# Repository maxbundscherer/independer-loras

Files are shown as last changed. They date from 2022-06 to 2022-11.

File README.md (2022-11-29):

# Independer

This repository is about a device called **Independer**. An Open-Source Project.

**Encrypted messaging & data sharing** via LoRaS & inexpensive hardware (ESP32). **Independent from mobile network & WIFI**. We use cheap *ESP32s*, *LoRa antennas*, *3D prototyping*, *mini keyboards* and develop our own encrypted *protocol* together with *software*.

**This page is intended for developers** - please visit the [official website](https://a-sdr.org/independer) for more information. If you want to **join, or have an idea**, feel free to [write us](mailto:maximilian@bundscherer-online.de) or [start a discussion](https://github.com/maxbundscherer/independer-loras/discussions). The current state of development can be viewed on the [project board](https://github.com/maxbundscherer/independer-loras/projects/2).

Presentation             |  Prototype-Video
:-------------------------:|:-------------------------:
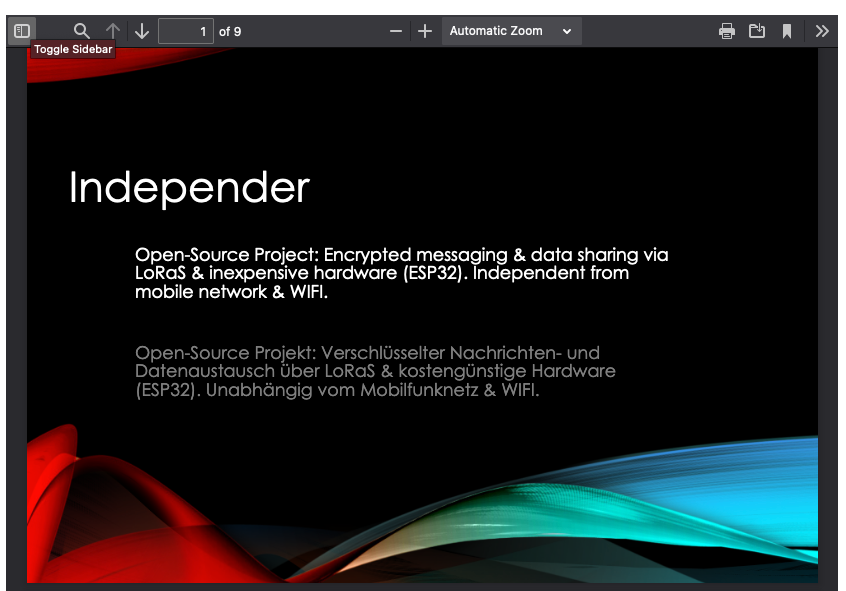
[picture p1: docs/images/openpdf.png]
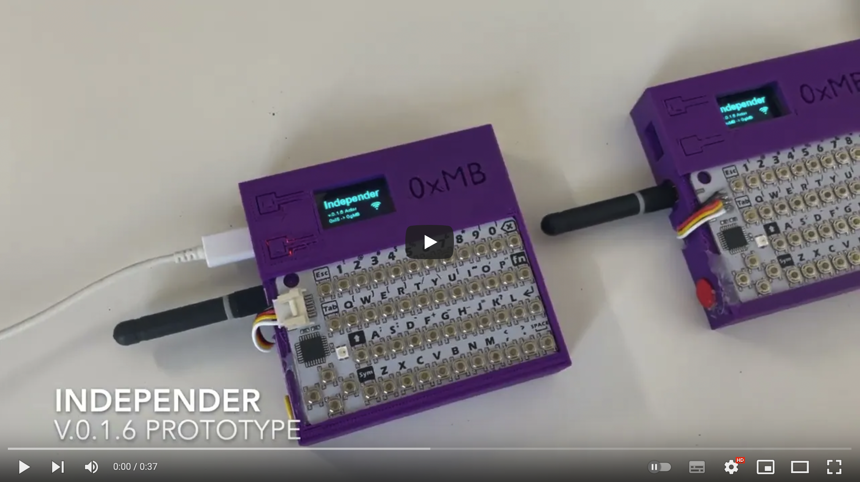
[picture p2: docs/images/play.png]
 | 

``esp32 - lora - encryption - short-message - protocol - keyboard - platformio - 3d-printing - independent``



Maintainer: [Maximilian Bundscherer](https://bundscherer-online.de)

## Overview

This repository describes the concept, the project structure, the encrypted LoraS transfer protocol (LoRaS) and the Independer application protocol. There are two type of devices: **Actor** (ID e.g. `0x01` or `0x02`) with keyboard & accumulator and **Gateway** (ID e.g. `0g01` or `0g02`) opt. with accumulator.

### Features

- **Actor to Actor (via LoRaS)**: Send messages directly between two Actors.
- **Actor to Gateway (via LoRaS)**: Send messages via Gateway. Actors can query their messages from Gateways.
- **Actor to Actor (via WIFI/Internet)**: Send messages via Internet. Actors can query their messages from WIFI/Internet.
- **Who is near me?** Scan the environment to find other Independers.
- **Many other functions**: Various test functions (Reachability Check, Reception & Transmission Evaluation), Update via WIFI, Notification LED, Deep Sleep Mode, Background-Sync, Battery Status, Send Quota & Gain, NTP-Time-Sync, Auto-Sync, Auto-Sleep, Contacts...

### Specifications

- Built on inexpensive Hardware
- Open-Source Software & Protocol
- Open-Source 3D-printed Case
- Multiple ESP32 boards, languages and frequencies are supported
- OLED-Screen
- LoRa & WIFI
- External Antenna Connector
- Mini Keyboard (QWERTY)
- 3000mAh LiPo Battery
- USB Charging (Micro-USB)

### Open-Source Project

Anyone can **contribute to the project** and **build their own device**. Many more features like GPS visualization, environment scanner, touch screen, alternative transmission and encryption functions are waiting **in the future**!

### Documentation

- [How-to, Hardware and Cost Overview](docs/howto.md)
- [Antenna Measurements](docs/antenna-measurements.md)
- [Update over WIFI](docs/update.md)
- [Developer Overview](docs/developer.md)
- [LoraS-Protocol](docs/loras-protocol.md)
- [Independer-Protocol](docs/independer-protocol.md)
- [Server-Protocol](docs/server-protocol.md)

The current state of development can be viewed on the [project board](https://github.com/maxbundscherer/independer-loras/projects/2).

### Included

- [Website](https://a-sdr.org/independer)
- [Documentation](docs/)
- [Sourcecode Independer ESP32 (C/C++)](independer-app/)
- [Sourcecode Independer Server (Python Flask Application)](independer-server/)
- [Docker Image Independer Server for Linux & Raspberry Pi](independer-server/)
- [3D-printed Case](case/)
- [Releases](https://github.com/maxbundscherer/independer-loras/releases/)

## More pictures

### Devices

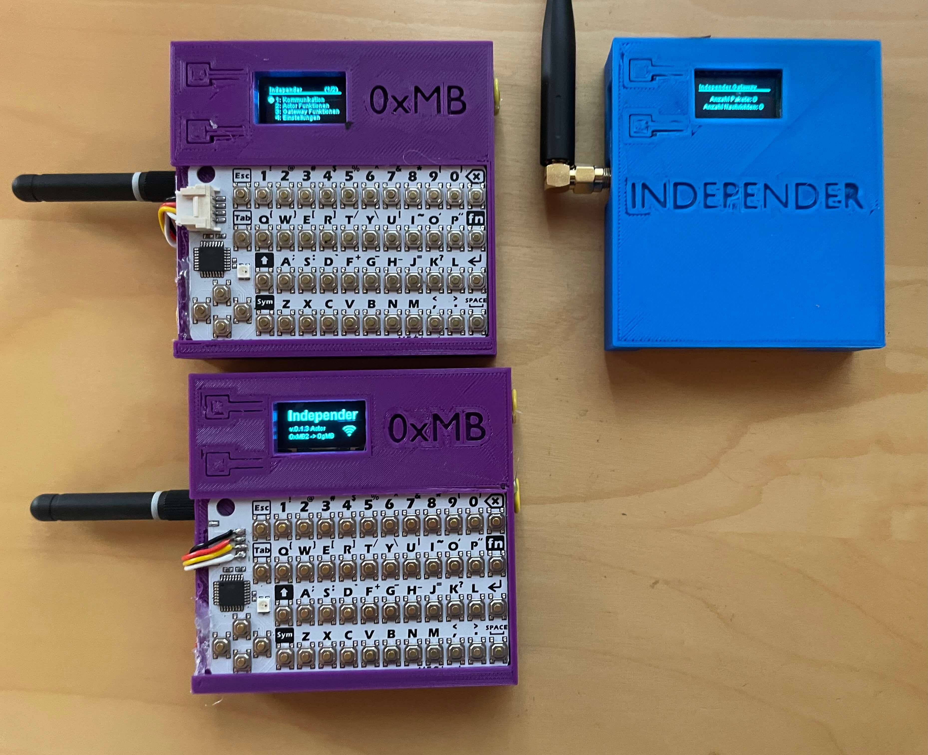
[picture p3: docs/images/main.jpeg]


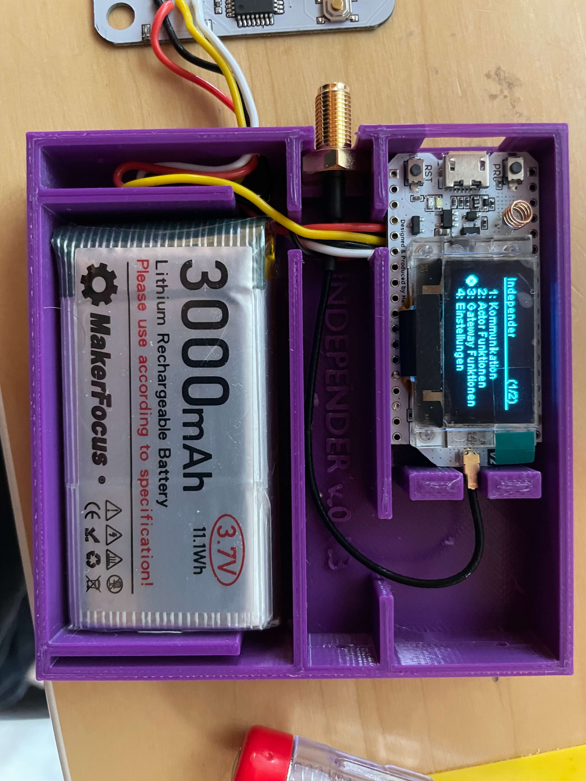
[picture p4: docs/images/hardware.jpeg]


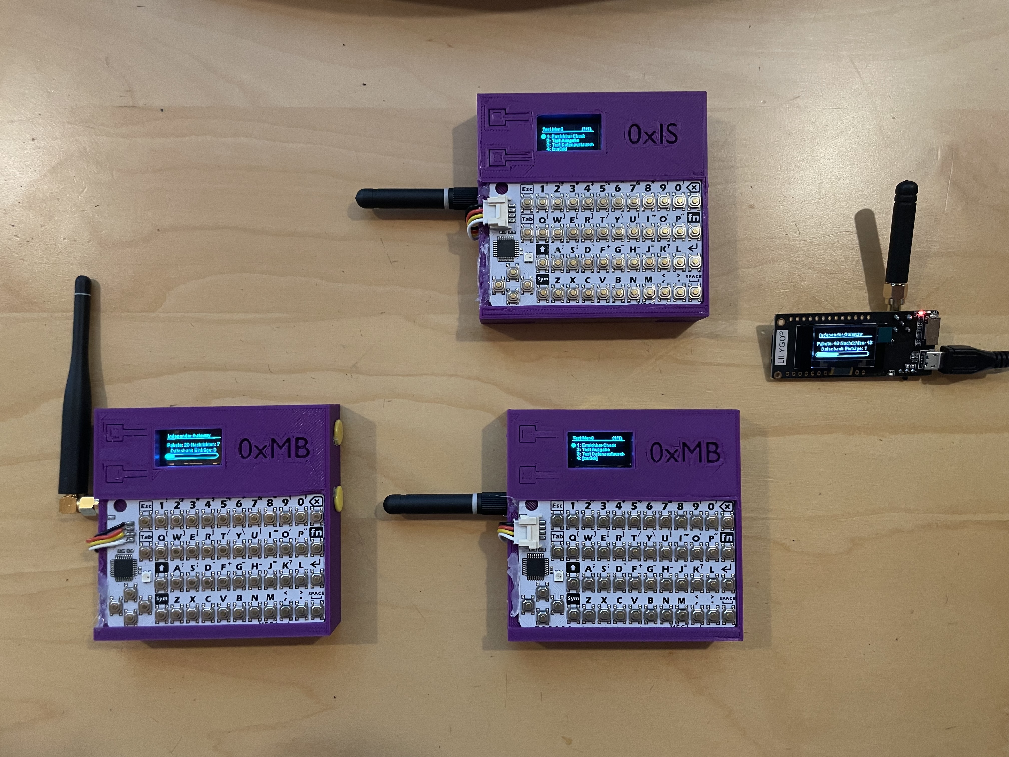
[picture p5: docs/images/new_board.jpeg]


### 3D Printing

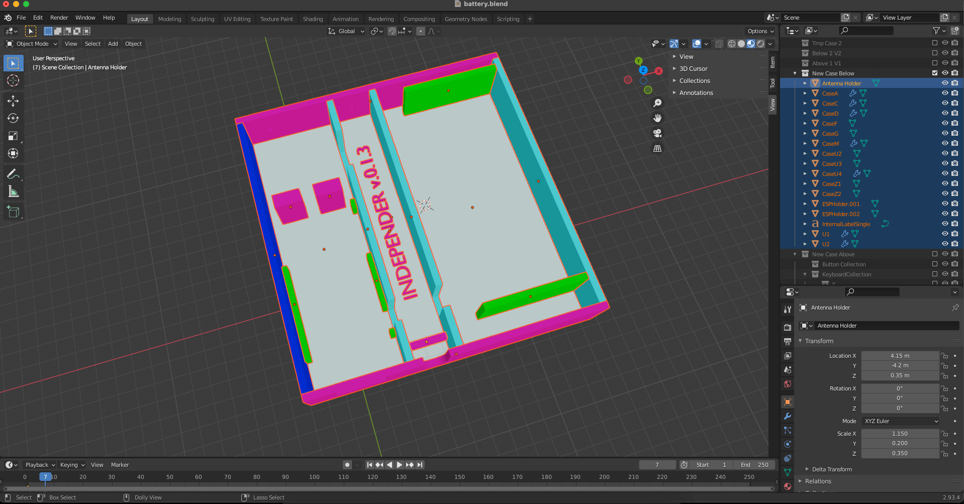
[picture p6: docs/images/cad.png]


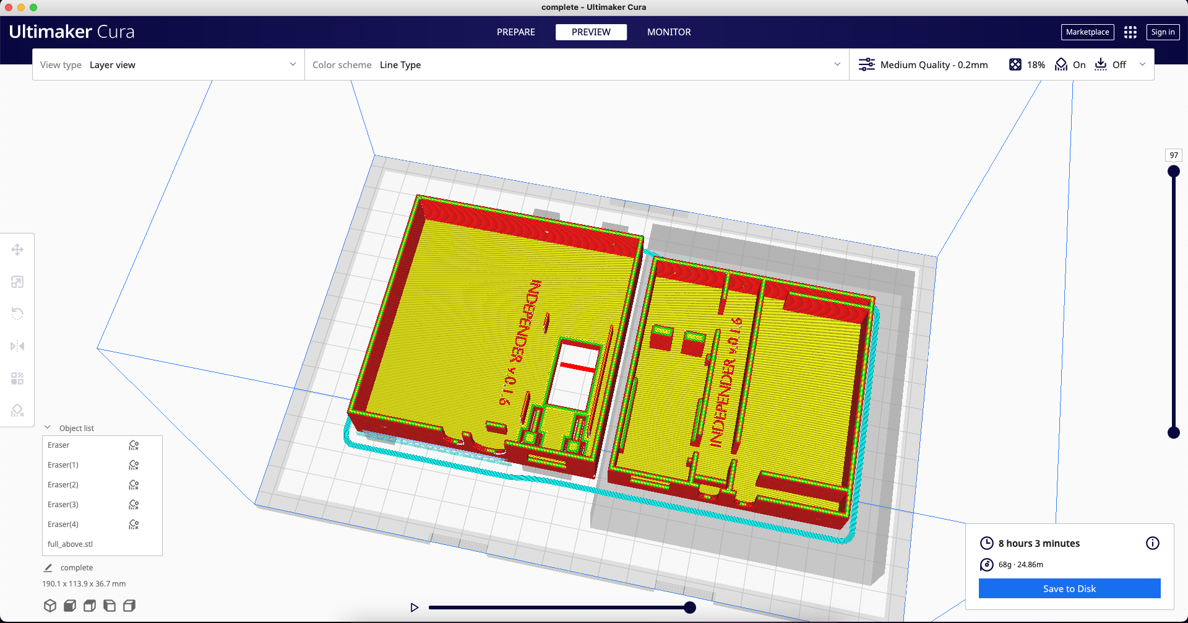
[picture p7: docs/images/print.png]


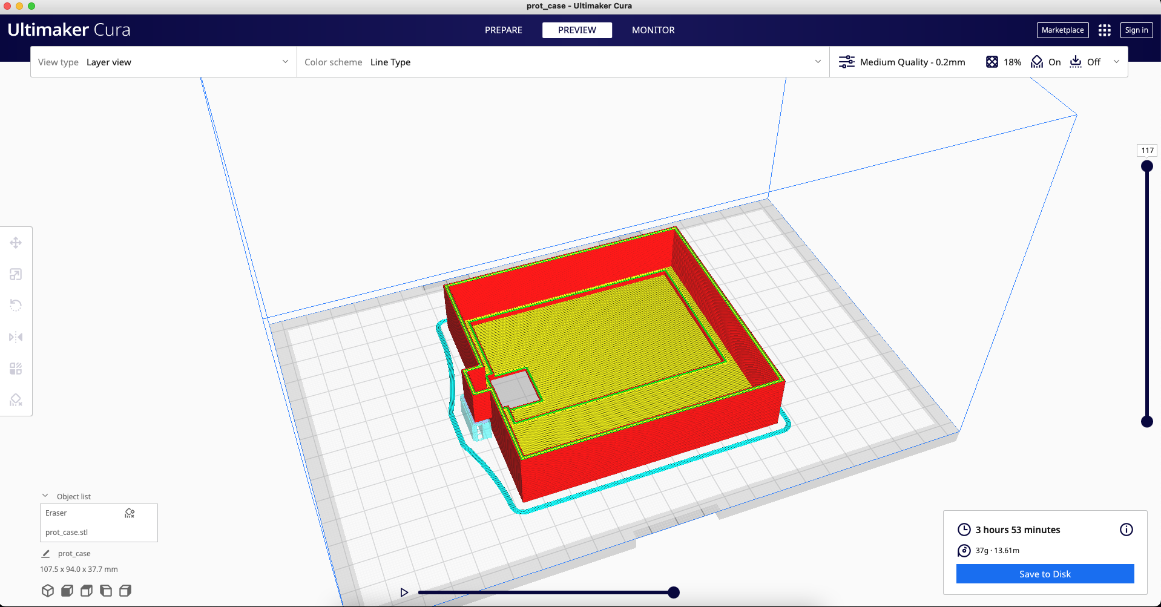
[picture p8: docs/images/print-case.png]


### UI

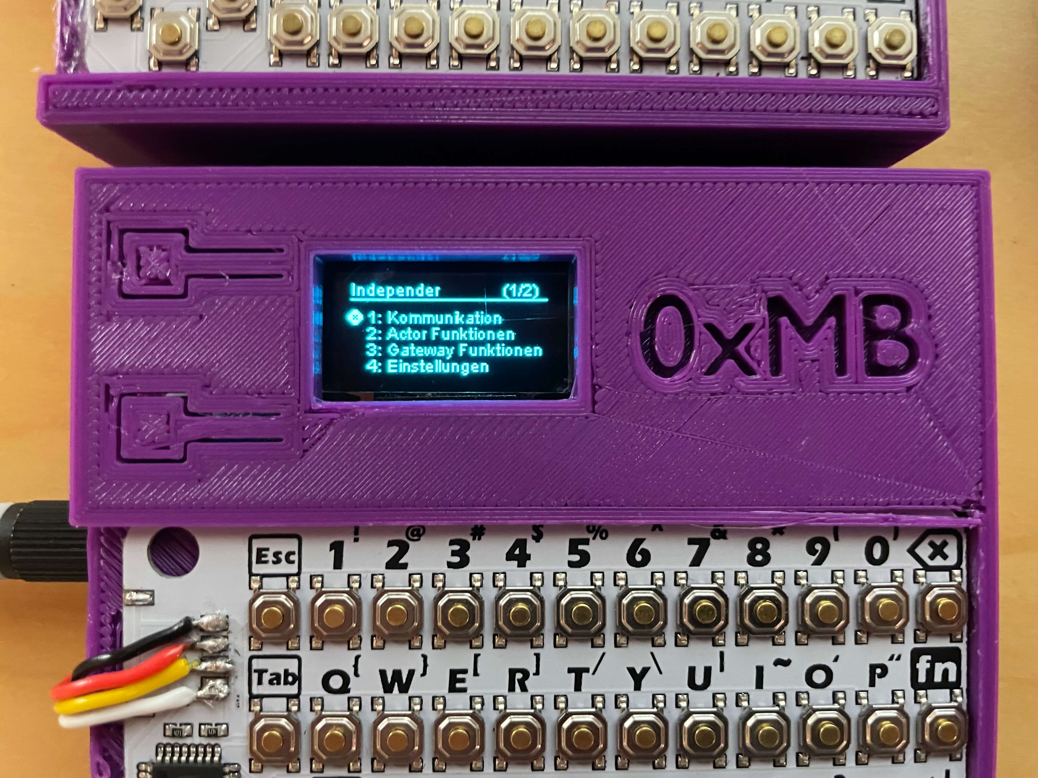
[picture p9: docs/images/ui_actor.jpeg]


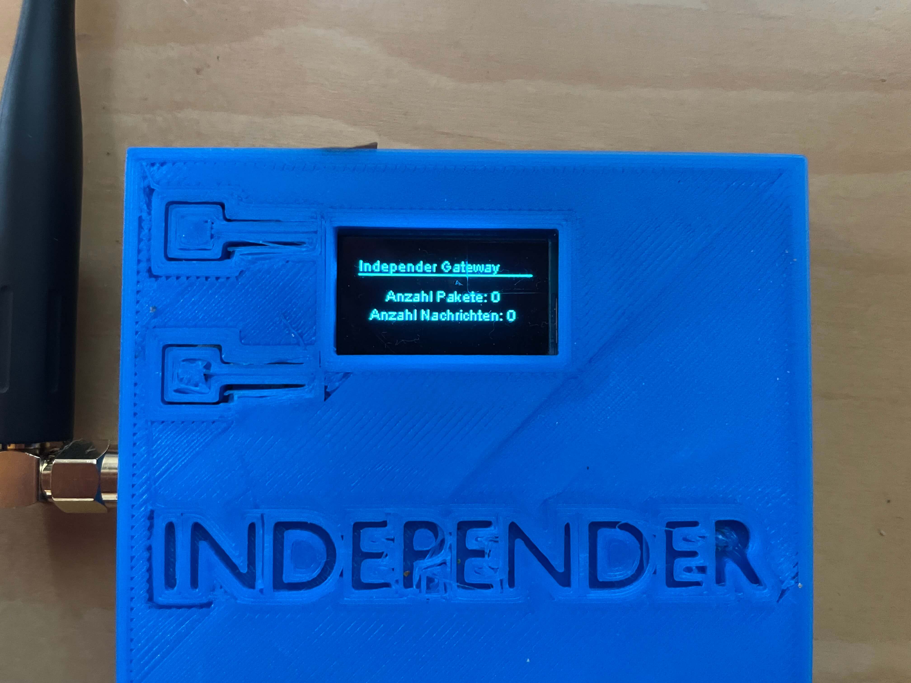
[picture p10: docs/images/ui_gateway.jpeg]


## Other

Also check out [Awesome/Automatic SDR](https://a-sdr.org/).

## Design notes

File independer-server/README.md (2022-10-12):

## Independer App Server

Docker is required.

### Run and Install

#### PreStep: Generate SSL Certificate

- `openssl req -x509 -newkey rsa:4096 -keyout key.pem -out cert.pem -sha256 -nodes` (set CN/FQDN to hostname)
- (Move `key.pem` and `cert.perm` to `./`)

#### Run

- Run `./run-raspbery.sh` on Raspberry Pi
- Run `./run-linux.sh` on Linux, macOs, etc.

##### Bugfix Raspberry TimeZone

If Postgres-Container does not sync time with Raspberry-Host - on Raspberry:

- `sudo vim /etc/apt/sources.list`
    - Add `deb http://raspbian.raspberrypi.org/raspbian/ testing main`
- `sudo apt-get update`
- `sudo apt-get install libseccomp2/testing`

#### Add Data

- Add Users and Gateways in table `users` and `gateways`
- Add System Info in table `systemdata`
    - `act_version`
    - `status_msg`

#### Config Network

- Config Router DNS to server (local ip)
- Config Router to forward port to server

### Status

- `docker ps -a`
- `docker compose ls`

### Stop and Clean

- Run `./clean-docker.sh`

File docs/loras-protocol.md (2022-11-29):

## LoRaS Protocol

This protocol is based on the **LoRa radio standard** and the transmission is currently **encrypted** with [boseji/xxtea-iot-crypt](https://registry.platformio.org/libraries/boseji/xxtea-iot-crypt). The goal will be an **asymmetric protocol like GPG**. Attention has always been paid to **low overhead**, **transmission security** and **energy saving**. The three protocols in this section are for LoRa receive and transmit (non-application level).

Currently the frequency **868 MHz** and **915 MHz** are used, but in the future the frequency **433 MHz** will also be usable. The frequencies are currently designed for the German area, but **can be freely selected**. Possible legal restrictions, such as the specified duty cycle and transmit power, can be taken into account, for example, using the *Send quota* and *Send gain* settings.

`[from]` and `[to]` in this section are realated to hardware-IDs, not application IDs. 

\[P1\] and \[P3\] are not suitable for background processing on actors. Please also visit [escape rules](escape-rules.md).

### Safe message \[P1\]

*Send message with hashcode-check*: Default protocol for e.g. Application messages.

`[num_packets]`, `[current_packet]`, and `[hashcode_msg]` are int-values.

- `[from]:[to]:+:[num_packets]`
- `[from]:[to]:[current_packet]:[part_of_msg]`
- `[from]:[to]:-:[hashcode_msg]`

### Unsafe short message \[P2\]

*Send short message without hashcode-check*: Default protocol for e.g. Who is in my area? or Is available?

Setting `[to]` to `*` addresses all devices in the environment.

- `[from]:[to]:s:[msg]`

### Unsafe single message \[P3\]

*Send single message without hashcode-check*: Default protocol for e.g. Respond to Who is in my area? and Is available?.

- `[from]:[to]:!:[msg]`

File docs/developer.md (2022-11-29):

## Developer Documentation

### Code Structure

The application is started through [PlatformIO](https://platformio.org/). Please set up parameters before compiling. Sourcecodes are located in `independer-app/src`.

- `device/`: Baseline LoRaS transmit & receive, Hardware stuff and UI.
- `workflow/`: Baseline workflow and examples for Actor and Gateway.
- `application/`: Baseline Independer application.

### Environments

- Environment label describes board-type (e.g. Heltec or TTGO), contains developer flag (release or developer), contains language flag and contains device-mode (actor or gateway).

#### Build and upload (single device)

- Select your specific PlatformIO-Enviroment.
- Run Task `Clean`
- Run Task `Build`
- Run Task `Upload`

#### Complete (all devices and all modes)

- Select no PlatformIO-Enviroment (global).
- Run Task `Clean`
- Run Task `Build`
- Run Script `independer-app/package.sh`
- View files in `independer-app/export/`

##### After Release (Release Workflow)

- Run previous steps.
- Merge `develop` into `master`.
- Create new release on GitHub (with files in `independer-app/export`).
- (Opt.) update Independer-Server.
- Increment Version in Independer-Server SQL-Table.
- Announcement new release (Signal, Facebook, Website, Product Presentation, GitHub)

### Upload code via WIFI

- See steps above.
- Upload ``independer-app/.pio/build/<BUILD-TYPE>/firmware.bin`` file via webbrowser (see update-doc).

### Additional Information

- [LoRa API](https://github.com/sandeepmistry/arduino-LoRa/blob/master/API.md)
- [Heltec LoRa API](https://github.com/HelTecAutomation/Heltec_ESP32/blob/master/src/lora/API.md)
- [Heltec API](https://github.com/HelTecAutomation/Heltec_ESP32/blob/master/src/oled/API.md)

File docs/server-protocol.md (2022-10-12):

## Server Protocol

JSON-API Independer Server. Please also visit [escape rules](escape-rules.md).

- `<server-url>/v1/register` (POST): Register Device
    - `id`: Independer-ID
    - `secret`: Secret
    - `version`: Version-String of Actor
    - Response `OK-<token>` (string, no json)

- `<server-url>/v1/getmsgs` (POST): Get all messages
    - `auth-id`: Independer-ID
    - `auth-token`: Token
    - Response (JSON-Array)
        - `receiver`: Receiver of the message
        - `author`: Author of the message
        - `msg`: Content of the message

- `<server-url>/v1/writemsg` (POST): Write a message
    - `auth-id`: Independer-ID
    - `auth-token`: Token
    - `receiver`: Receiver of the message
    - `msg`: Content of the message
    - Response `OK` (string, no json)

- `<server-url>/v1/clearmsgs` (POST): Clear all messages
    - `auth-id`: Independer-ID
    - `auth-token`: Token
    - Response `OK` (string, no json)

- `<server-url>/v1/gatewayregister` (POST): Check if Gateway is owned by the user
    - `auth-id`: Independer-ID
    - `auth-token`: Token
    - `gateway-id`: ID of Gateway
    - Response `OK` (string, no json) if allowed

- `<server-url>/v1/autosync` (POST): Get all messages
    - `auth-id`: Independer-ID
    - `auth-token`: Token
    - `version`: Version-String of Actor
    - `battery`: Battery mV of Actor
    - `time_before_sync`: Device time Actor before ntp sync
    - `time_after_sync`: Device time Actor after ntp sync
    - `dev_mode`: Dev mode activated
    - `is_actor`: IsActor
    - `wifi_ssid`: Wifi SSID
    - `boot_counts`: Boot Counts
    - Response (JSON-Array)
        - `num_msg`: Number of unread messages
        - `status_msg`: Status Broadcast
        - `act_version`: Independer-Version (last release)

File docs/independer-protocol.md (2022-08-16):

## Independer Protocol

Application level protocol is based on the [LoRaS Protocol](loras-protocol.md) \[P1\], \[P2\], and\[P3\]. Please also visit [escape rules](escape-rules.md).

### Based on Unsafe single message \[P3\]

#### Sleep Mode Gateway \[F3.1\]

This feature is used to set Gateway in sleep mode (Actor controlled).

1. For this Actor \[P3\] `[msg]` is set to `C;slp`. (send twice)

No available check before sending (\[F23.2\]). Gateway sends no response and goes into sleep mode. Gateway accepts these commands only from Gateway-Owner.

#### Clear User Messages on Gateway \[F3.2\]

This feature is used to clear user messages from Gateway (Actor controlled).

1. For this Actor \[P3\] `[msg]` is set to `C;clmsg`. (send twice)

No available check before sending (\[F23.2\]). Gateway sends no response and clears user messages.

#### Reset Gateway \[F3.3\]

This feature is used to reset Gateway.

1. For this Actor \[P3\] `[msg]` is set to `C;clgat`. (send twice)

No available check before sending (\[F23.2\]). Gateway sends no response and reset settings. Gateway accepts these commands only from Gateway-Owner.

### Based on Safe message \[P1\]

#### Update Gateway \[F1.1\]

This feature is used to update Gateway via wifi (Actor controlled).

1. For this Actor \[P1\] `[msg]` is set to `C;up;$wifiSSID;$wifiPW`. Where `$wifiSSID` is ssid from wifi and `$wifiPW` is wifi password.

No available check before sending (\[F23.2\]). Gateway sends no response and goes into update mode. Gateway accepts these commands only from Gateway-Owner.

#### Init Gateway \[F1.2\]

This feature is used to init Gateway via wifi (Actor controlled).

1. For this Actor \[P1\] `[msg]` is set to `C;init;$wifiSSID;$wifiPW;$id`. Where `$wifiSSID` is ssid from wifi, `$wifiPW` is wifi password and `$id` is gateway-id.

No available check before sending (\[F23.2\]). Gateway sends no response and initializes. Gateway-Owner is set from `[from]`.

### Based on Safe message \[P1\] and Unsafe single message \[P3\]

#### Send Message Actor to Gateway \[F13.1\]

This function is used to send messages via Gateway from Actor to Actor. This handles communication between Actor to Gateway (sending message).

1. For this Actor check if Gateway is available (\[F23.2\]).
2. If Gateway is available: Actor to Gateway \[P1\] `[msg]` is set to `M;$receiverId;$userMsg`. Where `$receiverId` is user-id from msg-receiver and `$userMsg` is actual message. Message author is derived from `[from]`.
3. Gateway to Actor \[P3\] `[msg]` is set to `A;ok`. (send twice)

If Actor does not receive a response from Gateway, Actor goes to step 2 (skip available check). This is repeated three times.

### Based on Unsafe single message \[P3\] and Safe message \[P1\]

#### Receive Messages Actor to Gateway to Actor \[F31.1\]

This function is used to send messages via Gateway from Actor to Actor. This handles communication between Actor to Gateway to Actor (receiving messages).

1. For this Actor \[P3\] `[msg]` is set to `Q;msg`. (send twice)
2. Gateway respond \[P1\] `[msg]` is set to `A;$numMessages;$msgAuthor1;$msgContent1;$msgAuthor2;$msgContent2;$msgAuthorN;$msgContentN`. Where `$numMessages` is number of message. If set `0` no messages are available. Messages with authors are appended to `[msg]` like `$msgAuthorN;$msgContentN`.  

No available check before sending (\[F23.2\]). This is repeated three times, if Actor receives no response from Gateway.

### Based on Unsafe short message \[P2\] and Unsafe single message \[P3\]

#### Who is in my area? \[F23.1\]

This function is used to find out which Actors and Gateways are nearby.

1. For this Actor \[P2\] `[to]` is set to `*` and `[msg]` is set to `?`.  (send twice)
2. Other devices (Actors and Gateways) respond randomly within 8 seconds \[P3\] and `[msg]` is set to `$battery-$rssi`. Where `$battery` is battery in mA and `$rssi` is rssi in dbi.

This is repeated threefold to reach and receive more devices. Designed for Actor background-job and Gateway.

#### Is available? \[F23.2\]

This function is used to find out whether a specific actor or gateway is nearby. Used mainly before sending a message over LoRaS.

1. For this Actor \[P2\] `[msg]` is set to `!`. (send twice)
2. Other device (Actors and Gateways) respond immedatly \[P3\] and `[msg]` is set to `$battery-$rssi`. Where `$battery` is battery in mA and `$rssi` is rssi in dbi. (send twice)

This function can be repeated. Designed for Actor background-job and Gateway.

### Based on Unsafe short message \[P2\], Safe message \[P1\] and Unsafe single message \[P3\]

#### Send Message Actor to Actor \[F213.2\]

This function is for sending messages directly between Actor A1 and Actor A2.

1. A1 (foreground) to A2 (background) \[P2\] `[msg]` is set to `T`. (send twice)
2. A2 reply to A1 \[P3\] `[msg]` is set to `S` and switch to foreground. (send twice)
3. A1 send data to A2 \[P1\] `[msg]` is set to `$msgContent`. Where `$msgContent` is content of message.
4. A2 replies to A1 \[P3\] `[msg]` is set to `N` and switch to background. (send twice)

Designed for Actor background-job. A1 tries whole process five times. A2 goes automatic in background if no data received from A1. If A2 receive data from step 1 - A2 reply \[P3\] to A1 `[msg]` is set to `S` again.

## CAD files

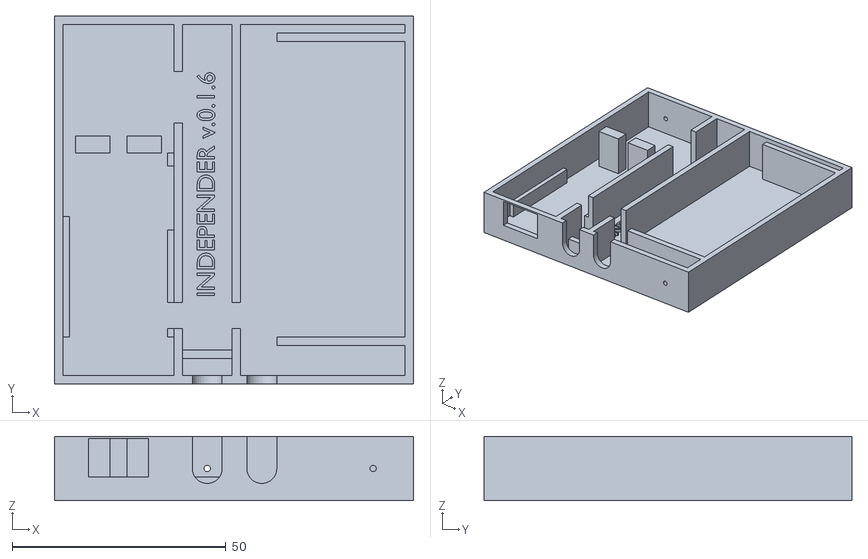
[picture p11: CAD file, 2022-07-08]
case/export/full_below.stl
84.0 x 86.0 x 15.0

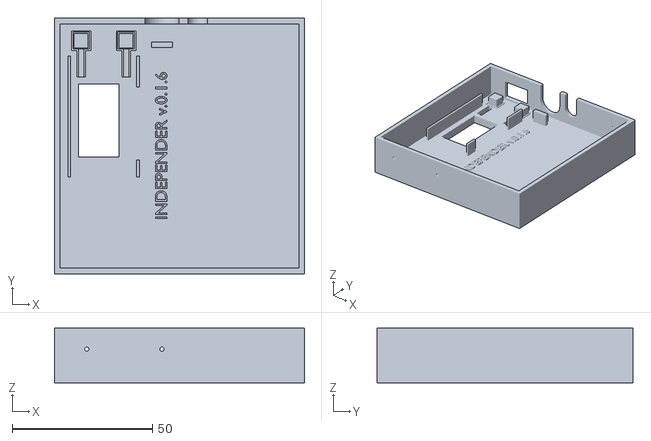
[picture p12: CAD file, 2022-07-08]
case/export/full_above.stl
89.0 x 91.0 x 19.5

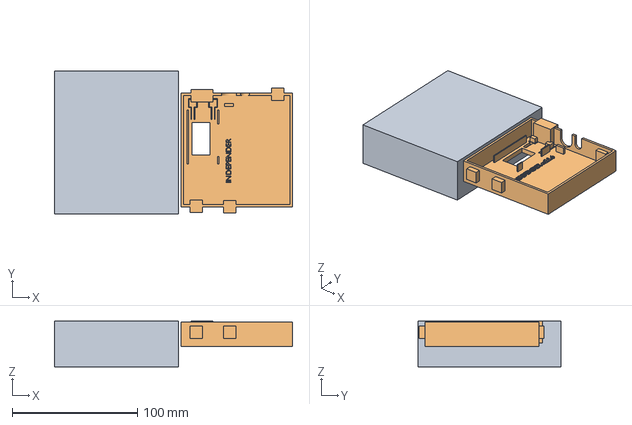
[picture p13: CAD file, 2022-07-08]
case/export/printer/complete.3mf
190.1 x 113.9 x 36.7 mm
full_below.stl
full_above.stl

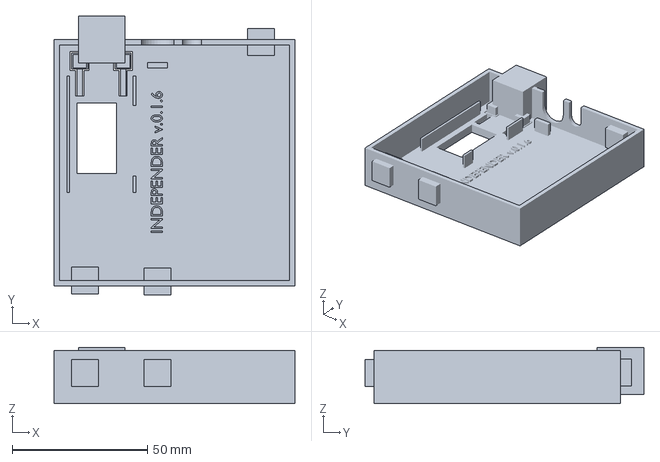
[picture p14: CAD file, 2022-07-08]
case/export/printer/full_above.3mf
89.0 x 102.9 x 20.7 mm

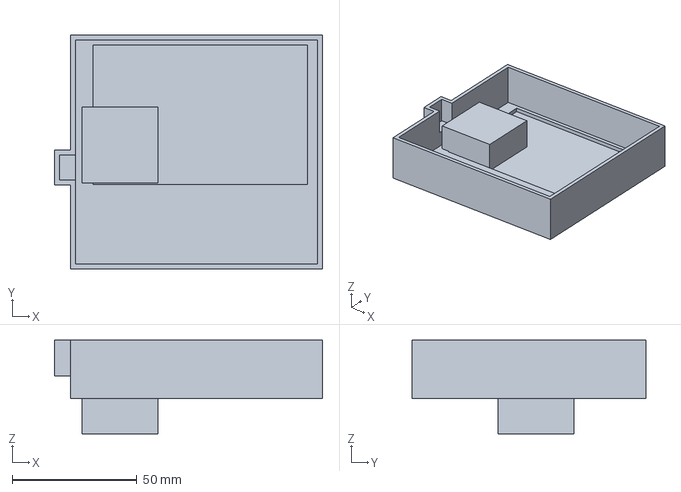
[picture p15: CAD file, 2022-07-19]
case/export/printer/prot_case.3mf
107.5 x 94.0 x 37.7 mm

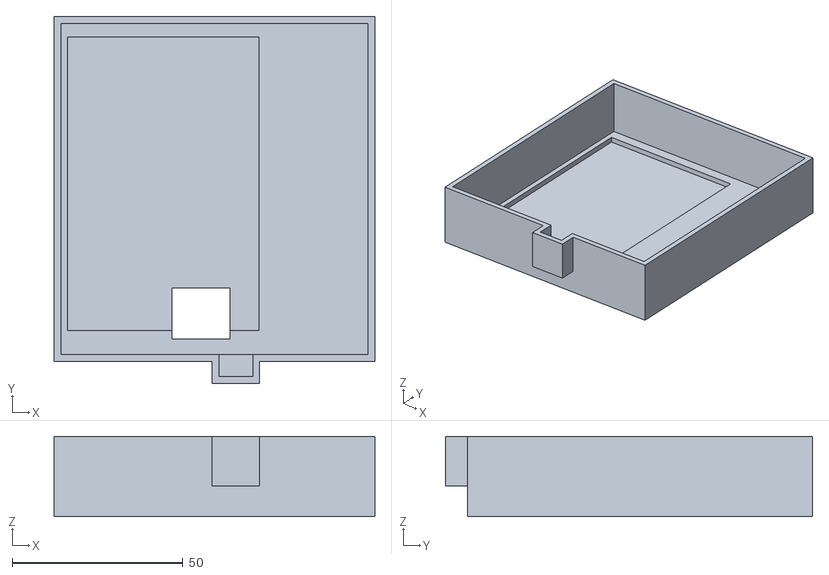
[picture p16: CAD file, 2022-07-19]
case/export/prot_case.stl
94.0 x 107.5 x 23.5

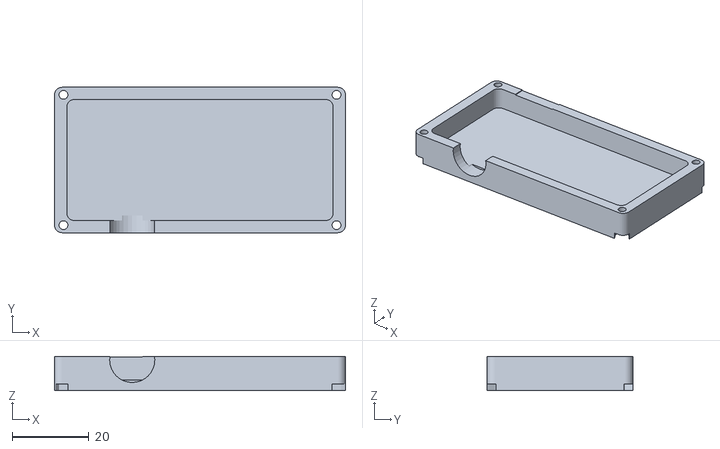
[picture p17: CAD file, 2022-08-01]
case/ttgo-case/LoRa-T3_case-bottom.stl
76.0 x 38.0 x 9.00

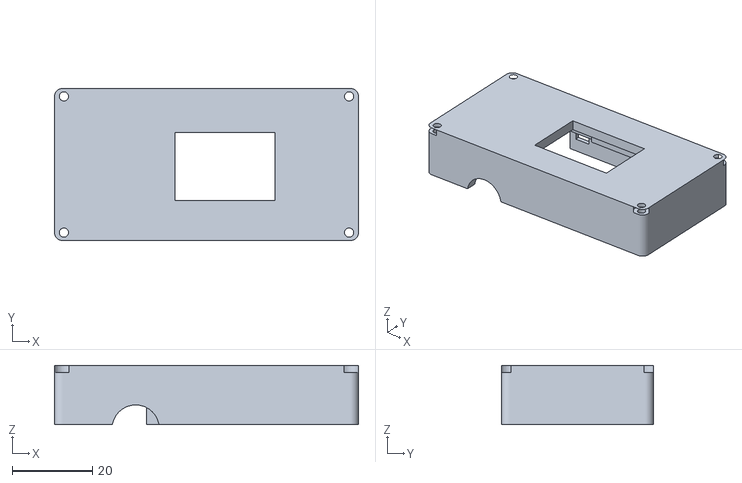
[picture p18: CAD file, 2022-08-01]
case/ttgo-case/LoRa-T3_case-cover.stl
76.0 x 38.0 x 14.8

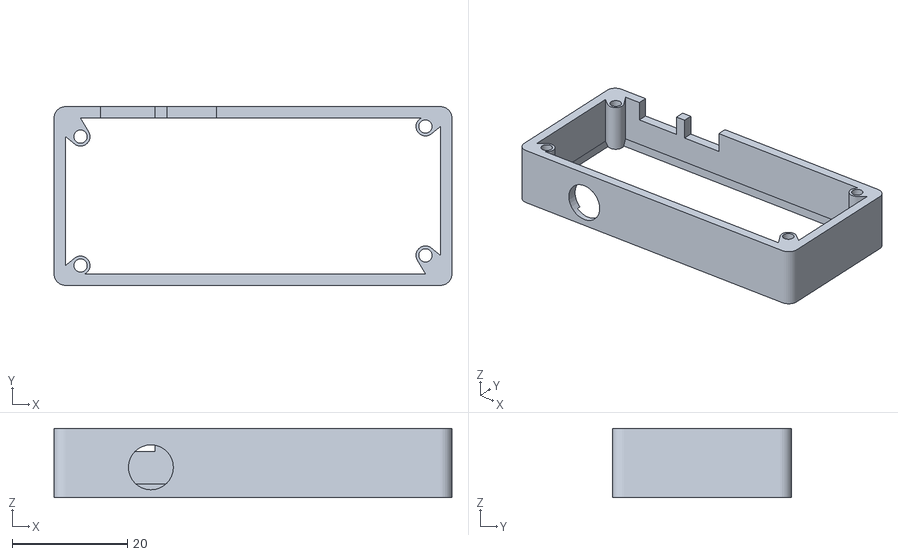
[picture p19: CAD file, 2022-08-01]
case/ttgo-case/LoRa-T3_case-inlay.stl
69.0 x 31.0 x 12.0

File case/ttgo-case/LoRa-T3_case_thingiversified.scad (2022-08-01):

// choose part to render
//part                = "case_inlay";
part                = "case_all";
//part                = "case_cover";
//part                = "case_bottom";

T3(part=part,cuts=cuts_t3);

// Fixed values - do not change
dim_t3_board        = [65,27,1.25];
uppers_t3           = 5;
lowers_t3           = 13;
dia_t3_screws       = 2.3;
loc_t3_screws       = [[2.6,1.45],
                       [dim_t3_board[0]-2.6,3.2,0],
                       [dim_t3_board[0]-2.6,dim_t3_board[1]-1.45,0],
                       [2.6,dim_t3_board[1]-3.2,0]];
cuts_t3             = [[[14.8,-8],[7.8,7.8],"front","rnd_indent"],  // antenna port
                       [[2.75,0],[8,3],"left","sqr_indent"], // usb port
                       [[13.4,0],[11.5,3],"left","sqr_indent"],  // sdcard/usb port
                       [[40.8,-dim_t3_board[2]-2.1],[4.65,2.1],"back","sqr_cone"],  // reset
                       [[49.5,-dim_t3_board[2]-4],[9.4,4],"back","sqr_cone"],// switch
                       [[24.6,4.5],[25,17],"top","sqr"]]; //display
space_t3_screws     = 1;


// Example values
// Render options
/*$fn              = 32;
case_part        = "case_all";
render_mode      = "normal";

// Board values
dim_board        = [60,30,2];
space_top        = 7;
space_bottom     = 3;
space_bscrew     = 1;

// Board Screw values
dia_bscrew       = 3.2;
loc_bscrews      = [[3.5,3.5],
                    [dim_board[0]-3.5,3.5],
                    [dim_board[0]-3.5,dim_board[1]-3.5],
                    [3.5,dim_board[1]-3.5]];                    

// Case Screw values
dia_cscrew       = 3;
dia_chead        = 5.5;
height_chead     = 2.5;
                    
// Case values
wall_frame       = 1.2;
rim              = 1;
mki              = 2;
                  
// Port values and locations
port_extend      = 20;
cuts             = [[[0,0],[5,3],"front","sqr_indent"],       
                    [[0,0],[5,3],"back","sqr_indent"],
                    [[0,0],[5,3],"left","sqr"],
                    [[0,0],[5,3],"right","sqr"],
                    [[0,0],[5,3],"top","sqr"],
                    [[0,0],[5,3],"bottom","sqr_indent"],
                    ];

case(part=case_part,
     render_mode=render_mode,
     
     wall_frame=wall_frame,
     rim=rim,
     mki=mki,
     port_length=wall_frame+rim,
     port_extend=port_extend,
          
     dim_board=dim_board,
     cuts=cuts,
     space_top=space_top,
     space_bottom=space_bottom,
     space_bscrew=space_bscrew,

     dia_cscrew=dia_cscrew,
     dia_chead=dia_chead,
     height_chead=height_chead,
     
     dia_bscrew=dia_bscrew,
     loc_bscrews=loc_bscrews);*/

//module to create openings for a electronics board
// d        - cube dimension [x,y,z] 
// cuts     - array of cuts to be created
// extend   - amount to extend outwards
// move     - move inwards(-)/outwards(+)
//
// cuts: 
//          [[[x,y],    // location
//            [x,y],    // size
//            side,     // side
//            shape],   // shape
//           [...],...]
//      
//      location:
//          x/y coordinates of lower left of opening,
//          meassured from the boards left top
//      size:
//          x/y dimension of the opening
//      side:
//          Side of the board, one of
//          front,back,left,right,top,bottom
//      shape:
//          shape of the opening, one of
//           square/rnd,
//           sqr_cone/rnd_cone,
//           sqr_indent/rnd_indent,
//           sqr_button/rnd_button

// Example
//    $fn=32;
//    board_dim=[20,20,1.5];
//    length=5;
//    extend=7;
//    move=0;
//    grow=4;
//    cut_location=[0,0];
//    cut_size=[3,2];
//    cuts=[[cut_location,cut_size,"front","sqr"],
//          [cut_location,cut_size,"back","sqr_cone"],
//          [cut_location,cut_size,"left","sqr_indent"],
//          [cut_location,cut_size,"right","sqr_button"],
//          [cut_location,cut_size,"top","rnd_indent"],
//          [cut_location,cut_size,"bottom","rnd_button"]];
//          
//    %cube(board_dim);
//    make_cuts_v2(dim=board_dim,
//                 cuts=cuts,
//                 length=length,
//                 extend=extend,
//                 move=move,
//                 grow=grow);

module make_cuts_v2(dim=[10,10,0],
                    cuts=[[[0,0],[10,10,10],"front","sqr"]],
                    length=1,
                    extend=0,
                    move=0,
                    grow=2){
                     
    for(cut=cuts){
        loc_x   = cut[0][0];
        loc_y   = cut[0][1];
        x       = cut[1][0];
        y       = cut[1][1];
        side    = cut[2];
        shape   = cut[3];
        

        if(side=="front" || side=="back" || side==0 || side==1) {
            translate([x/2,0,y/2]+[0,0,dim[2]]){        // move x,y to 0 and on top of board
                if(side=="front" || side==0)
                    translate([loc_x,0,loc_y])          // move to location
                        rotate([90,0,0])                // rotate up
                            translate([0,0,+length/2])       // move up to z=0
                                mkshape(x,y,length,shape,extend,move,grow);   // create centered shape

                if(side=="back" || side==1)
                    translate([dim[0]-x,0,0]+[-loc_x,0,loc_y])
                        rotate([270,0,0])
                            translate([0,0,+length/2+dim[1]])
                                mkshape(x,y,length,shape,extend,move,grow);
            }
        }

        if(side=="right" || side=="left" || side==2 || side==3 ) {
            translate([0,x/2,y/2]+[0,0,dim[2]]) {
                if(side=="right" || side==3)
                    translate([0,loc_x,loc_y]+[0,0,0])
                        rotate([90,0,90])
                            translate([0,0,+length/2+dim[0]])
                                mkshape(x,y,length,shape,extend,move,grow);
            
                if(side=="left" || side==2)
                    translate([0,dim[1]-x,0]+[0,-loc_x,loc_y])
                        rotate([90,0,270])
                            translate([0,0,+length/2])
                                mkshape(x,y,length,shape,extend,move,grow);
            }
        }

        if(side=="top" || side=="bottom" || side==4 || side==5 ) {
            translate([x/2,y/2,0]) {          
                if(side=="top" || side==4)
                    translate([loc_x,loc_y,0])
                        rotate([0,0,0])
                            translate([0,0,+length/2+dim[2]])
                                mkshape(x,y,length,shape,extend,move,grow);
                
                if(side=="bottom" || side==5)
                    translate([0,dim[1]-y,0]+[loc_x,-loc_y,0])
                        rotate([180,0,0])
                            translate([0,0,+length/2]) 
                                mkshape(x,y,length,shape,extend,move,grow);
            }
        }
    }
}
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

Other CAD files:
case/export/printer/full_below.3mf
case/case.blend

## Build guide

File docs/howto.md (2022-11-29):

## Introduction

### How to build your own device

-  Read `Hardware Overview` below.
- Print [3D-Case](../case/export).
- Connect antenna.
- (Opt. - on Actor) Connect the keyboard to the ESP32 board. Read `How to connect pins` below.
- (Opt. - on Actor) Connect the battery to the ESP32 board.
- Upload software to ESP32 board. Upload ``.bin`` file from [Releases](https://github.com/maxbundscherer/independer-loras/releases/) to ESP32 board. This is only necessary when initializing. After that, you can update via WIFI. See [Update-Doc](update.md).
- (Alternative) Upload software to ESP32 board. Read `Build and upload (single device)` in [Developer Overview](../docs/developer.md).
- When setting up the device for the first time, a configuration wizard is started automatically.
- For **some functions** like Online Chat, Update-Check, WIFI, NTP-Time-Sync and in order to use Gateways the **Independer must be registered**. **If you are not registered, it is only possible to communicate with other unregistered Independers.** (Read below). Use this [form](https://forms.gle/TChcaEvHBXyWu7XQA) to register your Independer.

### No Independer Registration

If the Independer is not registered, it will not run through the official Independer community.

**This means that you can only communicate with other Independers if they do not participate in the official community. Also the connection to the Independer Server for e.g. an update check or maintenance notes is not possible. In order to use Gateways and WIFI for e.g. NTP-Time-Sync, the Independer must also be registered.**

Unfortunately, this is technically necessary at the moment to ensure that, for example, no ID has been assigned twice in the official community.

Technically, unregistered Independers use a different sync word in LoRa connections. This means that they can only be heard by other unregistered Independers.

Use this [form](https://forms.gle/TChcaEvHBXyWu7XQA) to register your Independer.

## Hardware Overview

- Heltec ESP32 WiFi/LoRa v2 with OLED-Screen (SX1276 V2, 868-915MHz) ([Amazon](https://www.amazon.de/-/en/gp/product/B078M74NNN/)) (≈ 25 €)
- (alternative) LILYGO TTGO ESP32 (LoRa32 V2.1 1.6.1 Version LoRa ESP-32 OLED 0.96 Inch SD Card Bluetooth WiFi Module (868 MHz) ) ([Amazon](https://www.amazon.de/gp/product/B08T984WCT/)) (≈ 27 €)
- CardKB (U035, MEGA328P) ([Distrelec](https://www.distrelec.de/de/cardkb-mini-tastatureinheit-mega328p-m5stack-u035/p/30172534)) (≈ 7 €)
- (alternative) CardKB (U035-B, V1.1 MEGA8A) ([M5Stack](https://shop.m5stack.com/products/cardkb-mini-keyboard-programmable-unit-v1-1-mega8a)) (tests pending, but looks compatible) (≈ 7 €)
- Antenna Adapter (CAB.616) ([Mouser](https://www.mouser.de/ProductDetail/960-CAB.616)) (≈ 4 €)
- Antenna 1 (ANT-868-CW-RCL-SMA) ([Mouser](https://www.mouser.de/ProductDetail/712-ANT-868-CWRCLSMA)) (≈ 9 €)
- (opt.) Antenna 2 (ANT-868-CW-RH-SMA) ([Mouser](https://www.mouser.de/ProductDetail/712-ANT-868-CW-RHSMA)) (≈ 10 €)
- (opt.) LiPo Battery (Seamuing 3.7V 3000mAh) ([Amazon](https://www.amazon.de/gp/product/B08V11Z88Q/))
(≈ 10 €)

In total ≈ 45 - 55 € per device (without shipping).

## Connect pins

### Heltec Board

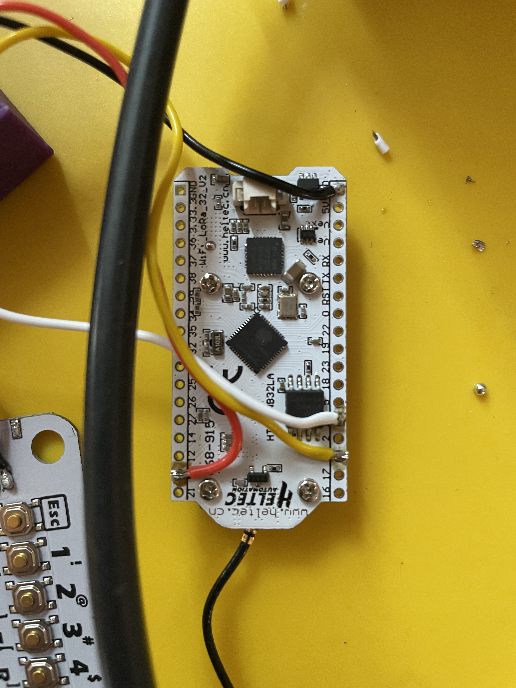
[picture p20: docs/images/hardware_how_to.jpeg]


### TTGO Board

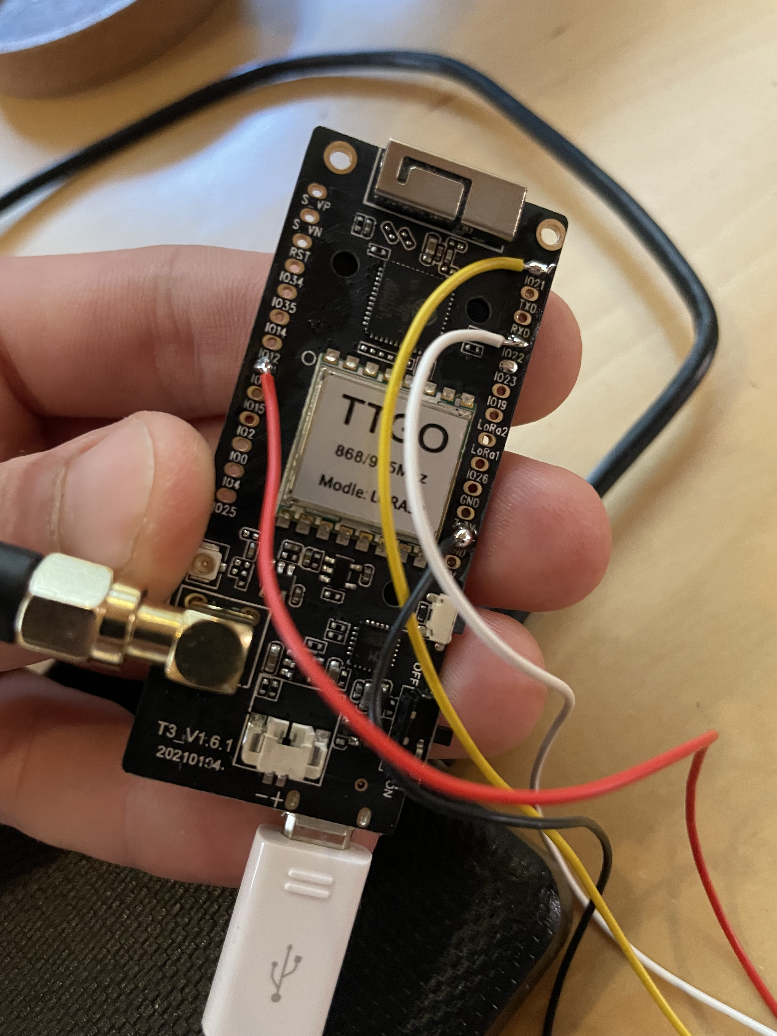
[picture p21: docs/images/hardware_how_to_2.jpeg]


### Keyboard



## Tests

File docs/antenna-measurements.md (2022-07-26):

## Antenna Measurements

### Overview

We tested three antennas:

- **Antenna 1** (ANT-868-CW-RCL-SMA) ([Mouser](https://www.mouser.de/ProductDetail/712-ANT-868-CWRCLSMA)) (≈ 9 €)
- **Antenna 2** (ANT-868-CW-RH-SMA) ([Mouser](https://www.mouser.de/ProductDetail/712-ANT-868-CW-RHSMA)) (≈ 10 €)
- **Antenna 3** LILYGO TTGO ESP32 (LoRa32 V2.1 1.6.1 Version LoRa ESP-32 OLED 0.96 Inch SD Card Bluetooth WiFi Module (868 MHz) ) ([Amazon](https://www.amazon.de/gp/product/B08T984WCT/)) (Antenna included in the package)

Two pieces of each antenna were measured to minimize or detect variations.

Reference Measurements (Open, Short and Load) below.

### Experiment

#### Antennas

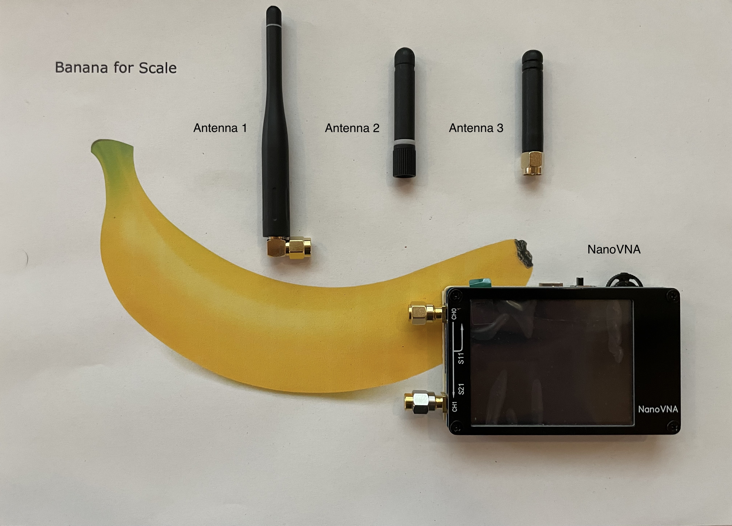
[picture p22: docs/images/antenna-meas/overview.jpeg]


#### Connect to NanoVNA

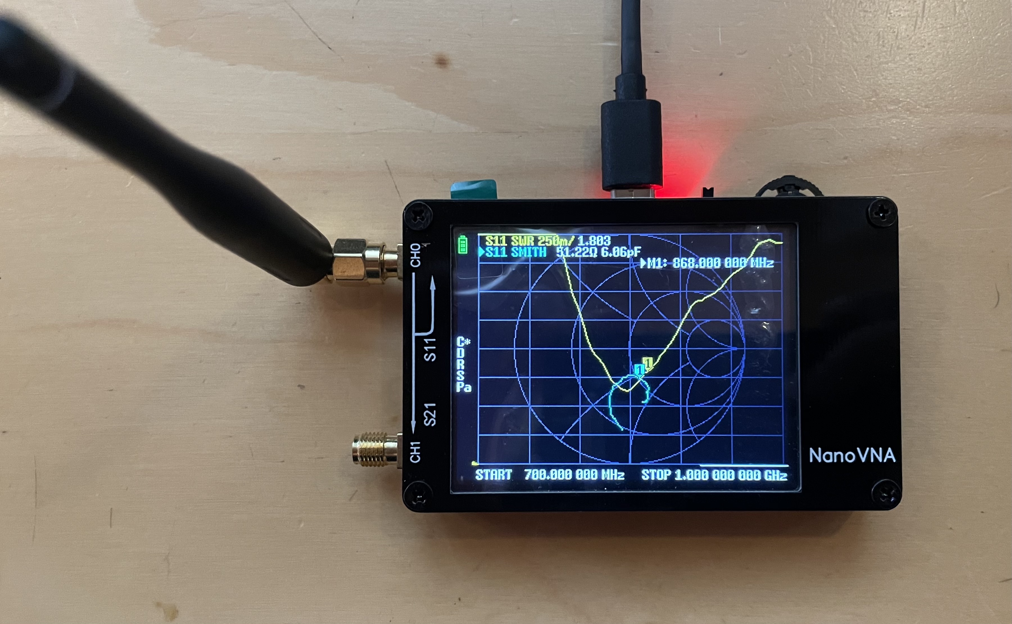
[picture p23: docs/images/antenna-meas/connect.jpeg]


### Parameters

#### Calibration

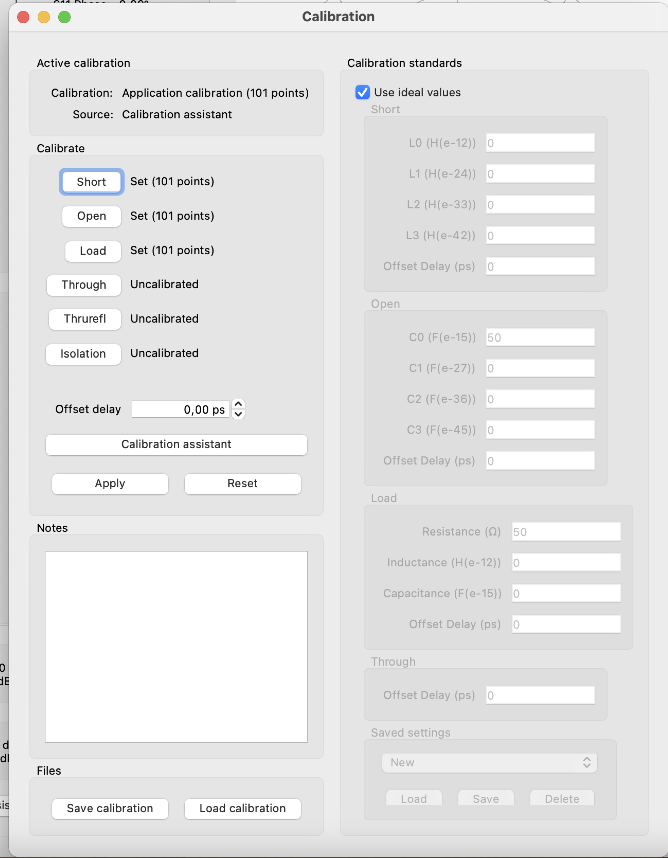
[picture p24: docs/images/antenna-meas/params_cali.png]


#### Sweep Configs

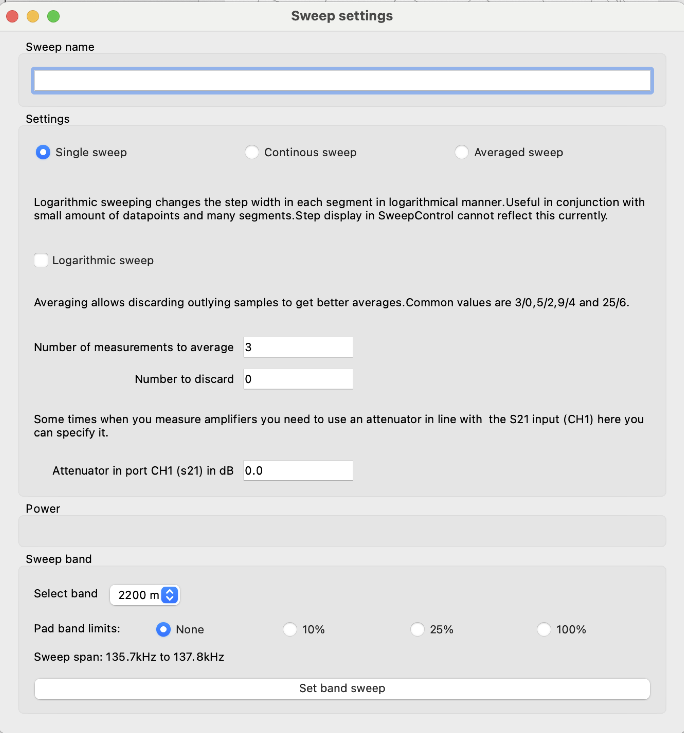
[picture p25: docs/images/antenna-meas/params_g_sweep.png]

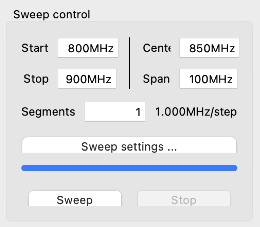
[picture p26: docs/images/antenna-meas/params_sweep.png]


### Results

#### Antenna 1

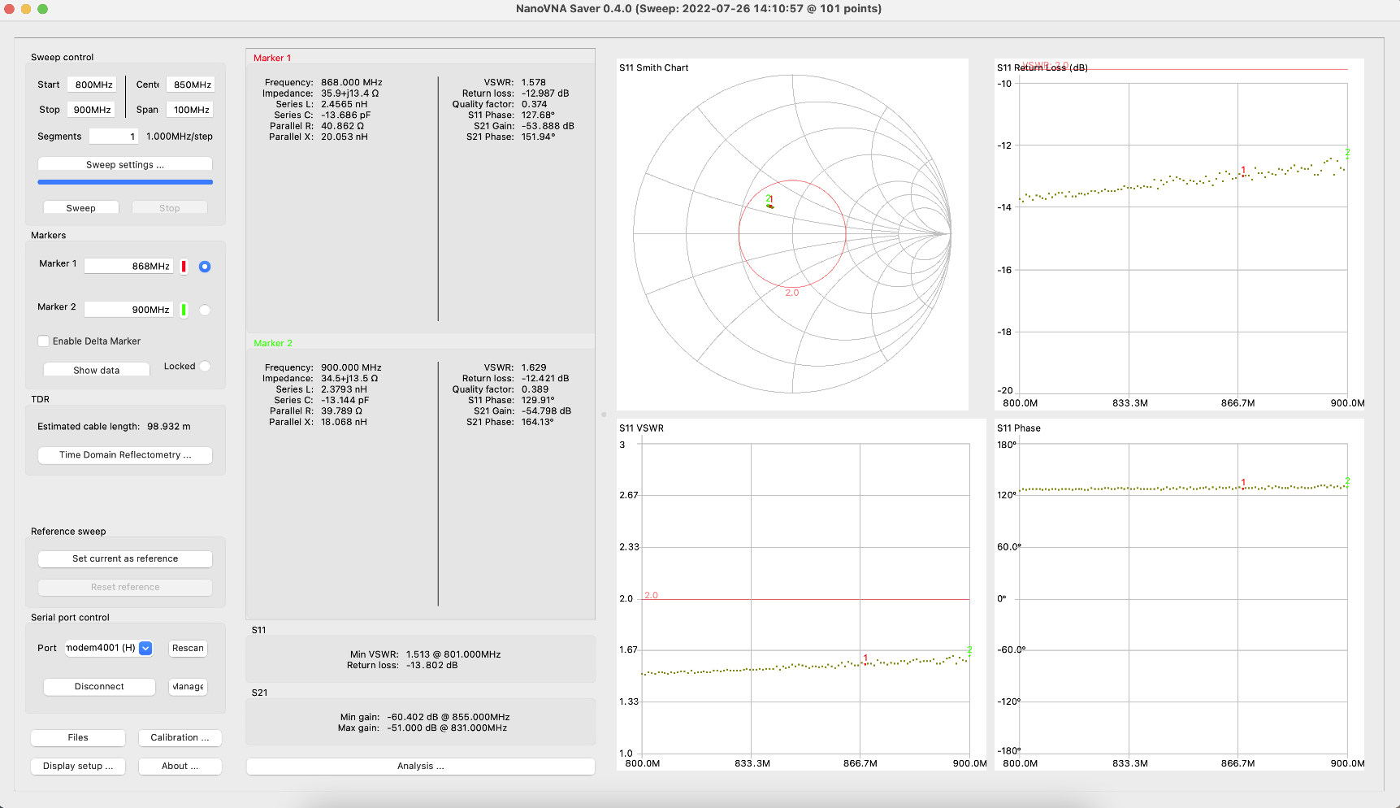
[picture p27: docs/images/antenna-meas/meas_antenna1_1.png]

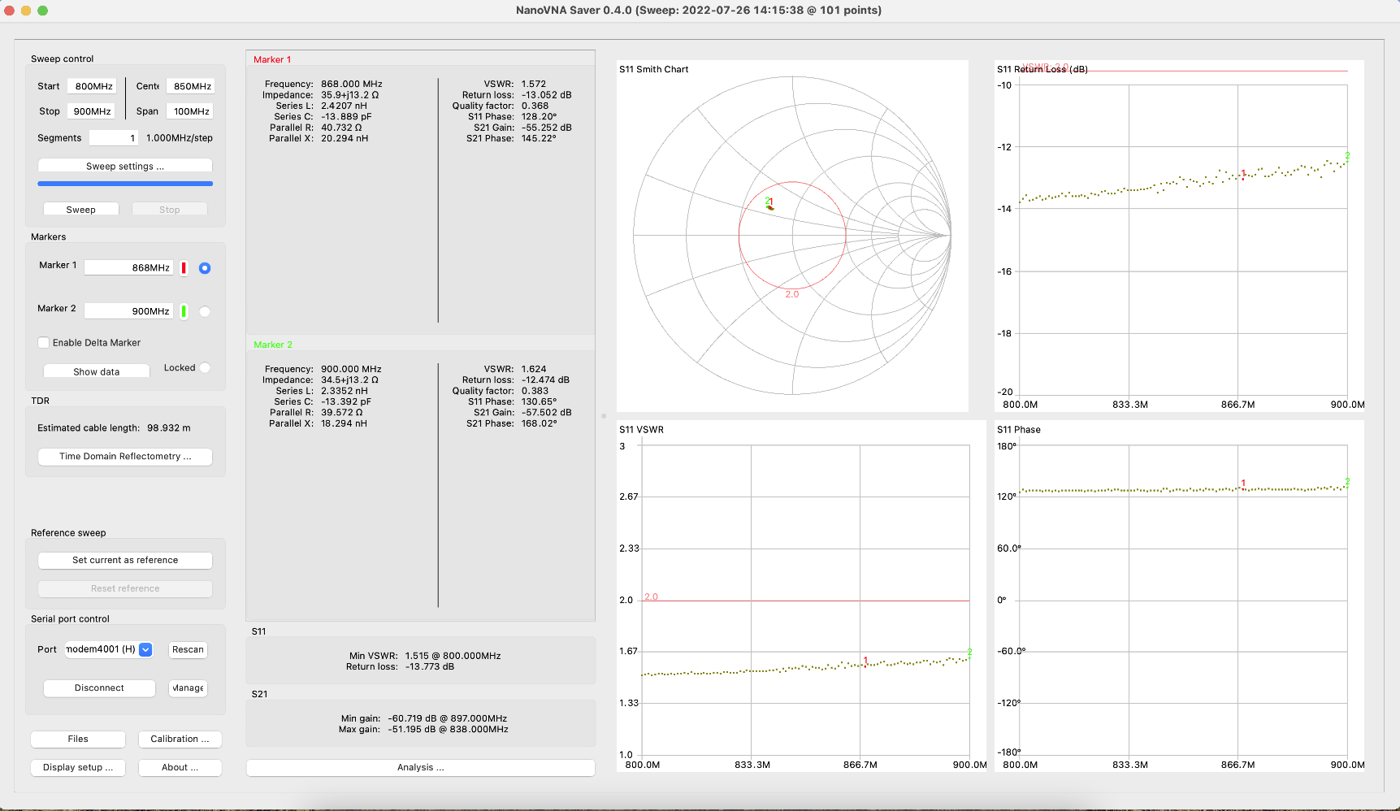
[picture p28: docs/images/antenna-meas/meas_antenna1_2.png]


#### Antenna 2

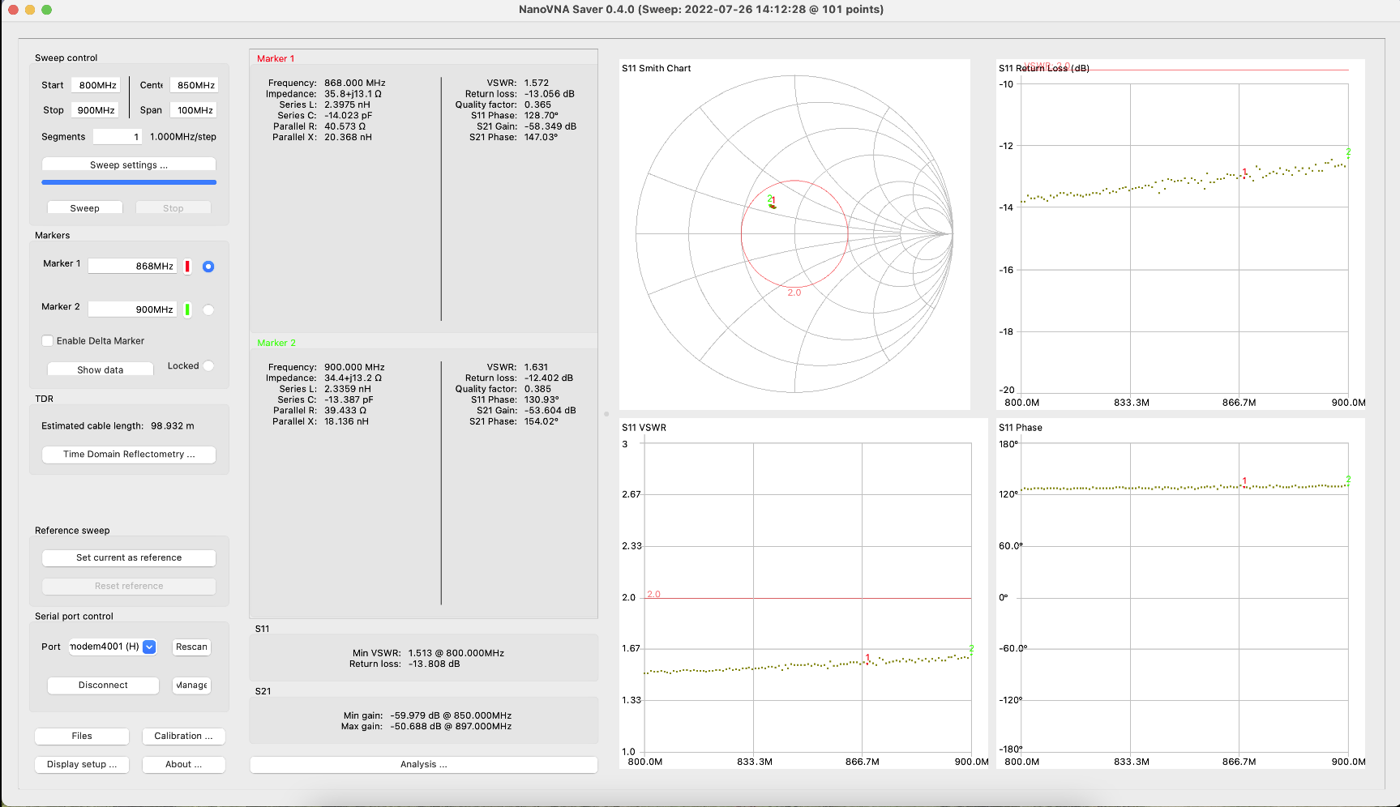
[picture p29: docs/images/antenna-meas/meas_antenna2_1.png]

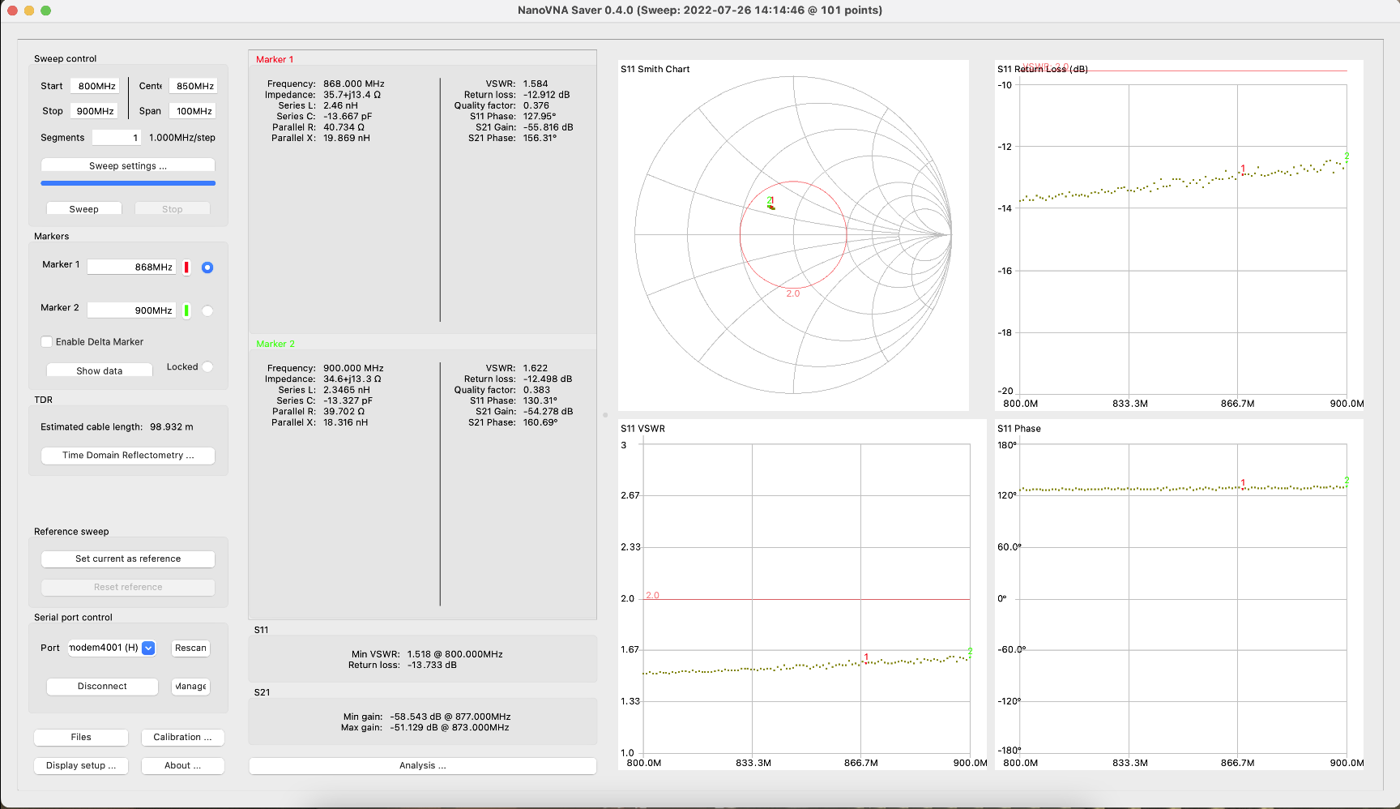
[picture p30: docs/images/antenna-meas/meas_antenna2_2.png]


#### Antenna 3

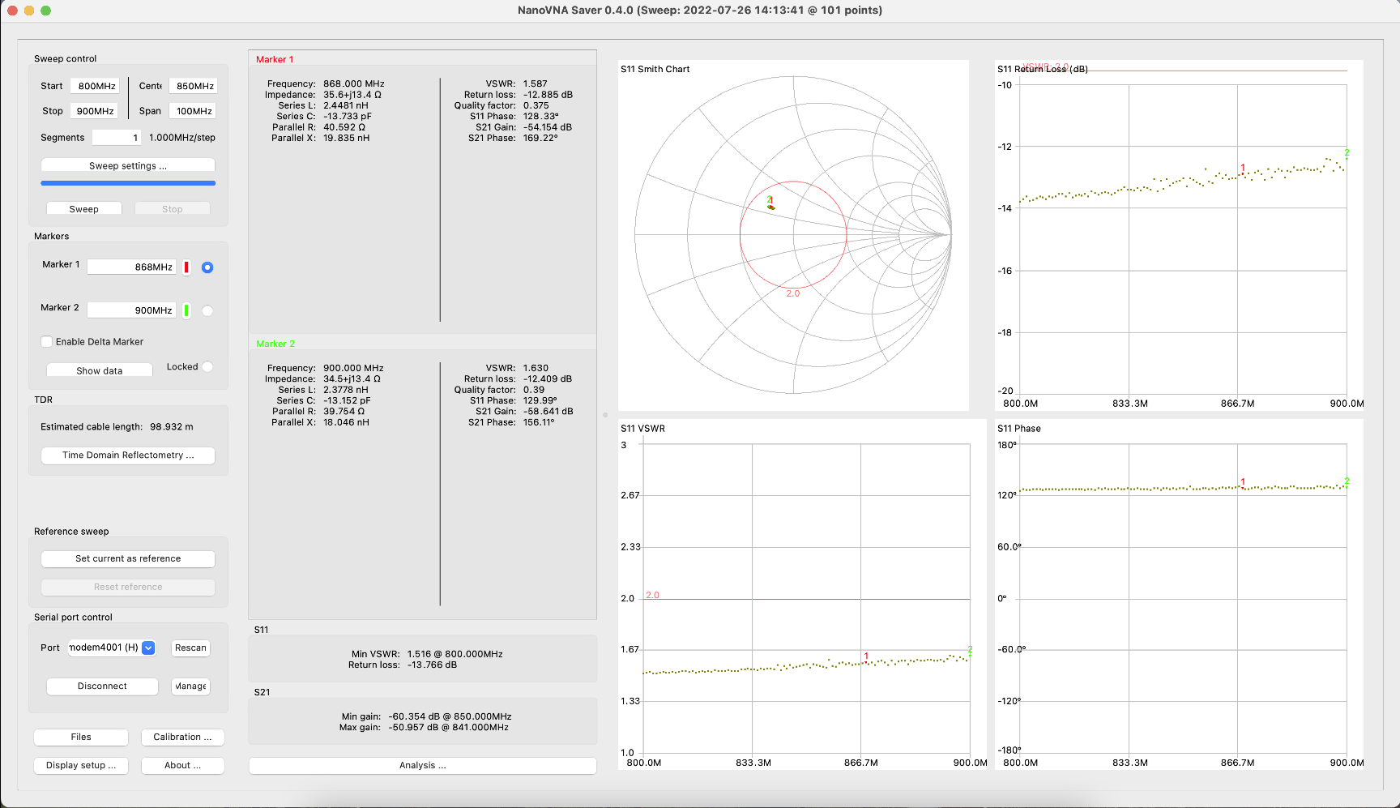
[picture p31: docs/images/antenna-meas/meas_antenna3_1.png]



### Ref Measurements

#### Open



#### Short



#### Load



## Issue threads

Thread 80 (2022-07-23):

Gain not working TTGO Boards

maxbundscherer, 2022-07-23:

Closed 2022-07-23.

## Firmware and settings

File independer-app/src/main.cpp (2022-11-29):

#include <SPI.h>
#include <Wire.h>
#include "SSD1306Wire.h"
#include <LoRa.h>
#include <ArduinoJson.h>
#include "device/mb-i18n.h"
#include "device/mb-utils.h"

#if IS_RELEASE
boolean c_dev_mode = false;
#else
boolean c_dev_mode = true;
#endif

#if IS_ACTOR
boolean c_actor_mode = true;
#else
boolean c_actor_mode = false;
#endif

// TODO: LillgoGo Actor noch testen
// TODO: Hashcode Check verbessern

/*
 * ####################################
 *  Config Section
 * ####################################
 */
// Product Config
String c_product_version = "v.0.3.8";

/*
 * ####################################
 *  State Section
 * ####################################
 */
String state_my_id = "0x01";         // Saved in db and INIT CONFIG (fixed)
String state_gateway_id = "0g01";    // Saved in db and INIT CONFIG
String state_gateway_owner = "0x01"; // Saved in db and INIT CONFIG
String state_wifi_ssid = "";         // Saved in db and INIT CONFIG
String state_wifi_pw = "";           // Saved in db and INIT CONFIG

String state_wifi_hostname = "independer-" + String(utils_random_int(10000));

int state_lora_gain = 20; // Supported values are between 2 and 17 for PA_OUTPUT_PA_BOOST_PIN, 0 and 14 for PA_OUTPUT_RFO_PIN - Saved in db

int state_oled_brightness = 255;  // saved in db
int state_auto_sleep_enabled = 1; // saved in db

String state_wifi_server_url = "independer.ddns.net"; // saved in db (fixed)
int state_wifi_server_port = 5001;                    // saved in db (fixed)
int state_wifi_server_timeout = 10000;                // saved in db
String state_wifi_server_device_token = "";           // saved in db and INIT CONFIG
bool state_is_registered_independer = false;          // saved in db and INIT CONFIG (fixed)

#include "device/mb-time.h"
#include "device/mb-base64.h"
#include "device/mb-gui.h"
#include "device/mb-crypt.h"
#include "device/mb-lora.h"
#include "device/mb-wifi.h"

/*
 * ####################################
 *  Setup Section
 * ####################################
 */

// Database
#include "device/mb-database.h"

// OTA
#include "device/mb-ota.h"

// Common
#include "application/application-independer.h"
#include "workflow/workflow-independer.h"

// Actor
#include "workflow/workflow-multi-actor.h"
#include "application/application-actor.h"
#include "workflow/workflow-actor.h"

// Gateway
#include "application/application-gateway.h"
#include "workflow/workflow-gateway.h"

void setup()
{

  boolean isFirstBoot = workflow_independer_init(c_actor_mode, c_product_version, c_dev_mode);

  if (!c_dev_mode)
  {
    if (isFirstBoot or !c_actor_mode)
    { // Show every boot on gateway
      gui_logo_static(c_product_version, state_my_id, state_gateway_id, c_actor_mode, state_gateway_owner);
      delay(C_GUI_DELAY_STATIC);
    }
  }
  else
  {
    gui_msg_animated(I18N_INFO_TITLE, I18N_BOOT_DEV_ACTIVE, C_GUI_DELAY_MSG_VERY_SHORT_I);
  }

  if (c_actor_mode)
    multi_actor_start();
}

/*
 * ####################################
 *  Loop Section
 * ####################################
 */
void loop()
{

  if (c_actor_mode)
  {
    workflow_actor_main_menu();
  }
  else
  {
    workflow_gateway_main();
  }
}

// TODO: Bug Senden fällt bei Actoren im Background aus (vielleicht mal bei Verwendung von sendLaster bei Near me ?)
// TODO: Bug Hostname bei WIFI wird nicht übertragen

// TODO: Warum Faktor 2 und 8 Multi Task Decoding

// TODO: Verbesser Start/Stop Actor Multi in Briefe abrufen
// TODO: UI Verbessern Leerzeichen bei Long Text ausgabe und Text Eingabe

// TODO: Refactoring c_id und Gateway id
// TODO: Refactoring disableShortcuts bei gui_selection wieder ausbauen, hat nicht funktioniert

// TODO: String compare wie in workflow-actor implementieren!

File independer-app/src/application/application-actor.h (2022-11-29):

/*
 * ####################################
 *  Who is near? Section
 * ####################################
 */

struct S_I_Application_Device_Item
{
  String deviceId;
  String deviceMsg;
  String receivedRssi;
  String attempt;
};

void application_actor_who_is_in_my_area()
{

  boolean sync_was_on_flag = multi_actor_get_state();

  if (sync_was_on_flag)
  {
    multi_actor_stop();
  }

  int c_max_ping_retries = 3;                                                             // Maximial attempts to receive
  int c_max_ping_delta = C_INDEPENDER_RES_BETWEEN_DELAY_ACTOR;                            // Waiting 1ms between receiving
  int c_max_ping_max_receive_attempts = (C_INDEPENDER_SCAN_MS + 2000) / c_max_ping_delta; // Waiting approx C_INDEPENDER_SCAN_MS seconds for next packet

  S_I_Application_Device_Item collected_db[30];
  int collected_counter = 0;

  int l_attempt = 0;
  while (l_attempt < c_max_ping_retries)
  {
    l_attempt++;

    lora_send_msg_short_message(state_my_id, "*", C_INDEPENDER_SHORT_MESSAGE_CHAR_ALL, state_lora_gain);
    delay(C_INDEPENDER_SEND_DELAY_REPEAT);
    lora_send_msg_short_message(state_my_id, "*", C_INDEPENDER_SHORT_MESSAGE_CHAR_ALL, state_lora_gain);

    gui_display_prg_static(I18N_ACTOR_APP_ENV_SCAN, l_attempt, 0, c_max_ping_retries);

    int l_cur_receive_attempt = 0;
    while (l_cur_receive_attempt < c_max_ping_max_receive_attempts)
    {
      l_cur_receive_attempt++;

      int packetSize = LoRa.parsePacket();

      if (packetSize)
      {

        String i_res = "";
        while (LoRa.available())
        {
          i_res += LoRa.readString();
        }

        ParserAnsTuple parser_ans = lora_stateful_parse(i_res, state_my_id);

        if (parser_ans.message != "")
        {
          struct S_I_Application_Device_Item ret = {
              parser_ans.from,
              parser_ans.message,
              String(LoRa.packetRssi(), DEC),
              String(l_attempt)};
          collected_db[collected_counter] = ret;
          collected_counter++;
        }
      }

      delay(c_max_ping_delta);
    }
  }

  if (collected_counter > 0)
  {
    String gui_items[collected_counter + 1]; // Add + 1 (go back item)

    for (int i = 0; i < collected_counter; i++)
    {
      String r = collected_db[i].attempt + ": (" + collected_db[i].deviceId + ") '" + collected_db[i].deviceMsg + I18N_ACTOR_APP_ENV_SCAN_RS + collected_db[i].receivedRssi;
      // Serial.println("Scan Item '" + r + "'");
      gui_items[i] = r;
    }

    gui_items[collected_counter] = I18N_MENU_GO_BACK; // Add go back item

    boolean hasComp = false;
    while (!hasComp)
    {
      S_GUI_SELECTION_ITEM selected_wrapper = gui_selection(I18N_ACTOR_APP_ENV_SCAN_OUTPUT_T, gui_items, collected_counter - 1 + 1, false); // Add + 1 (go back item)
      if (selected_wrapper.success == false or selected_wrapper.value == collected_counter)
        hasComp = true;
      else
        gui_msg_long_text(I18N_ACTOR_APP_ENV_SCAN_DETAIL_T, gui_items[selected_wrapper.value]);
    }
  }

  if (sync_was_on_flag)
  {
    multi_actor_start();
  }
}

/*
 * ####################################
 *  Is Available Section
 * ####################################
 */

/**
 * @return boolean return if is available
 */
boolean application_actor_is_available(String target_id, boolean flagHideAns, String testSendMsg = C_INDEPENDER_SHORT_MESSAGE_CHAR_SINGLE, int maxRetries = 5, String responseMsgCheck = "", boolean checkResponse = false)
{

  boolean sync_was_on_flag = multi_actor_get_state();

  if (sync_was_on_flag)
  {
    multi_actor_stop();
  }

  int c_max_ping_retries = maxRetries;                                                    // Maximial attempts to receive pong message
  int c_max_ping_delta = C_INDEPENDER_RES_BETWEEN_DELAY_ACTOR;                            // Waiting 1ms between receiving
  int c_max_ping_max_receive_attempts = (C_INDEPENDER_SEND_DELAY * 4) / c_max_ping_delta; // Waiting approx 2 seconds for next packet

  String receivedMsg;
  boolean receivedSuccess = false;

  int l_attempt = 0;
  while (l_attempt < c_max_ping_retries and !receivedSuccess)
  {
    l_attempt++;

    gui_display_prg_static(I18N_ACTOR_APP_REACH_CH_ATTEMPT, l_attempt, 0, c_max_ping_retries);

    lora_send_msg_short_message(state_my_id, target_id, testSendMsg, state_lora_gain);
    delay(C_INDEPENDER_SEND_DELAY_REPEAT);
    lora_send_msg_short_message(state_my_id, target_id, testSendMsg, state_lora_gain);

    int l_cur_receive_attempt = 0;
    while (l_cur_receive_attempt < c_max_ping_max_receive_attempts and !receivedSuccess)
    {
      l_cur_receive_attempt++;

      boolean appendDebug = !checkResponse;

      struct S_APP_PONG pong_ans = application_independer_pong(target_id, appendDebug);

      if (pong_ans.receivedSomething)
      {
        l_cur_receive_attempt = 0;
      }

      if (pong_ans.receivingCompleted and (!checkResponse or strcmp(pong_ans.message.c_str(), responseMsgCheck.c_str()) == 0)) // TODO: String compare wie in workflow-actor implementieren!
      {
        receivedMsg = pong_ans.message;
        receivedSuccess = true;
      }
      else
      {
        delay(c_max_ping_delta);
      }
    }
  }

  if (receivedSuccess and !flagHideAns)
  {
    gui_msg_animated(I18N_ANS_TITLE, receivedMsg, C_GUI_DELAY_MSG_MIDDLE_I);
  }
  else if (!flagHideAns)
  {
    gui_msg_animated(I18N_ERROR_TITLE, I18N_ACTOR_APP_REACH_ERR_NO_RES, C_GUI_DELAY_MSG_MIDDLE_I);
  }

  if (sync_was_on_flag)
  {
    multi_actor_start();
  }

  return receivedSuccess;
}

/*
 * ####################################
 *  Send Message to Gateway Section
 * ####################################
 */
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

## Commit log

2022-07-08 improve case
    [battery.blend]
2022-07-19 improve protection case
    [case.blend, prot_case.3mf, prot_case.stl]
2022-07-23 replace crypt and update to v.0.2.2
    [main.cpp]
2022-07-23 Update to v.0.2.4 and fix gateway sleep mode
    [main.cpp, mb-utils.h]
2022-07-23 Update to v.0.2.5 and fix duplication env scan response
    [main.cpp]
2022-07-24 Implement Res Messages and Bugfix Response
    [application-actor.h, mb-wifi.h]
2022-07-26 Add antenna meas
2022-07-26 Add antenna results
2022-08-01 Add new case files
    [LoRa-T3_case-bottom.stl, LoRa-T3_case-cover.stl, LoRa-T3_case-inlay.stl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]
2022-08-03 Update to v.0.3.1 and fix battery state
    [main.cpp, mb-utils.h, workflow-independer.h]
2022-08-09 Implement register on device

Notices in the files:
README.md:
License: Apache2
